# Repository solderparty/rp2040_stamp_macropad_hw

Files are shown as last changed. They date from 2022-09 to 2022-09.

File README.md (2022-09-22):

# RP2040 Stamp MacroPad (Flux Project)

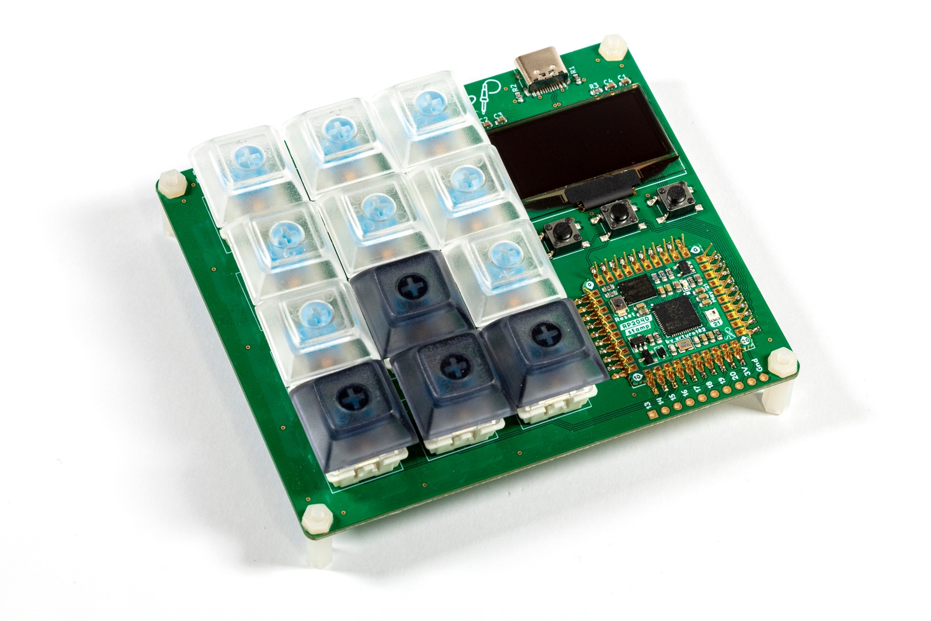
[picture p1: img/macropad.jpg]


Just add switches and key caps and you have a 3x4 MacroPad powered by the RP2040 Stamp, each key footprint includes a individually addressable **NeoPixel**, the board also comes with a **1.3" 128x64 OLED**, **three function buttons**, and extra GPIOs on an **optional header**. 

The board features a 3-in-1 combo RP2040 Stamp footprint, meaning you can solder the Stamp directly using the SMD pads, use 2mm pin headers, or using our FlexyPins!

You can program it using Arduino or CircuitPython.

# What does "Flux Project" mean?

At Solder Party, we always want to get interesting products in people's hands. However, releasing a product is no easy feat, we need to make sure everything is polished, provide documentation, examples, and extensive support.

With Flux, we want to streamline the process a bit, get fun projects into everyone's hands quicker.

Flux projects are more experimental in nature. While they are tested and verified, the documentation might not be fully there, and the examples might be very basic. 
Flux projects are targeted at people who are not scared to put a bit of extra work into getting the project to where they want it to end up.
These projects are also produced in smaller quantities, there is no guarantee there will be more produced in the future. Even if there is a new batch, it might differ from the initial version. 

These projects are in constant Flux, so to speak.

If there is enough interest, a Flux project might become a fully-fledged Solder Party product in the future, but there is no guarantee.

# Links

For more information visit https://flux.solder.party/

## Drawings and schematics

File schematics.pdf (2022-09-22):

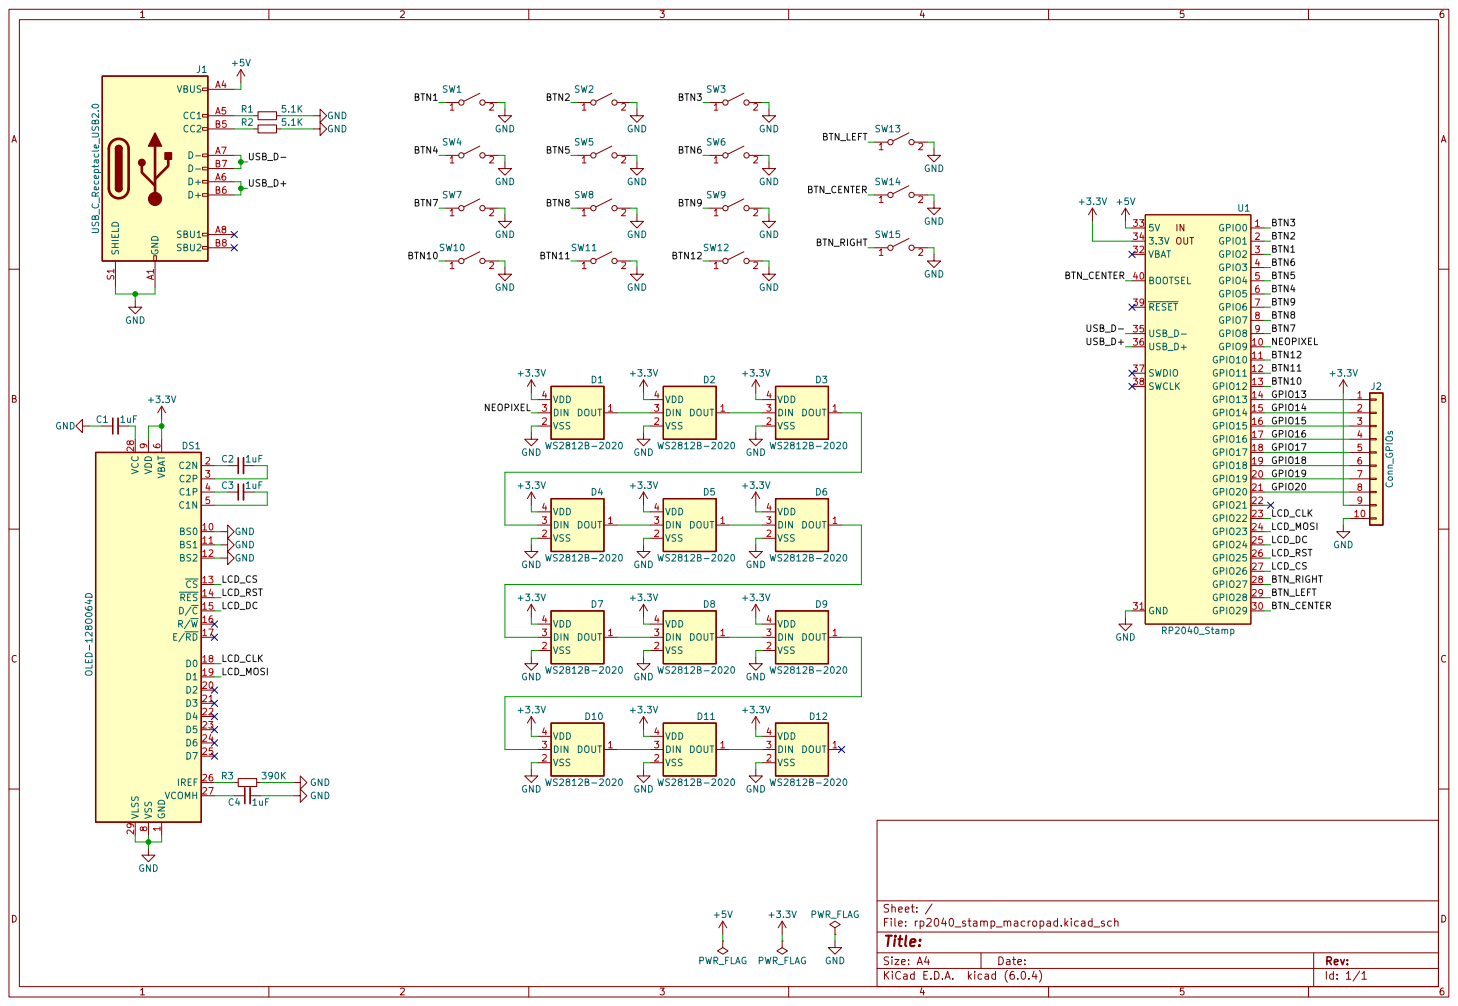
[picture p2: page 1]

J2 Conn_GPIOs GND GND GND GND GND

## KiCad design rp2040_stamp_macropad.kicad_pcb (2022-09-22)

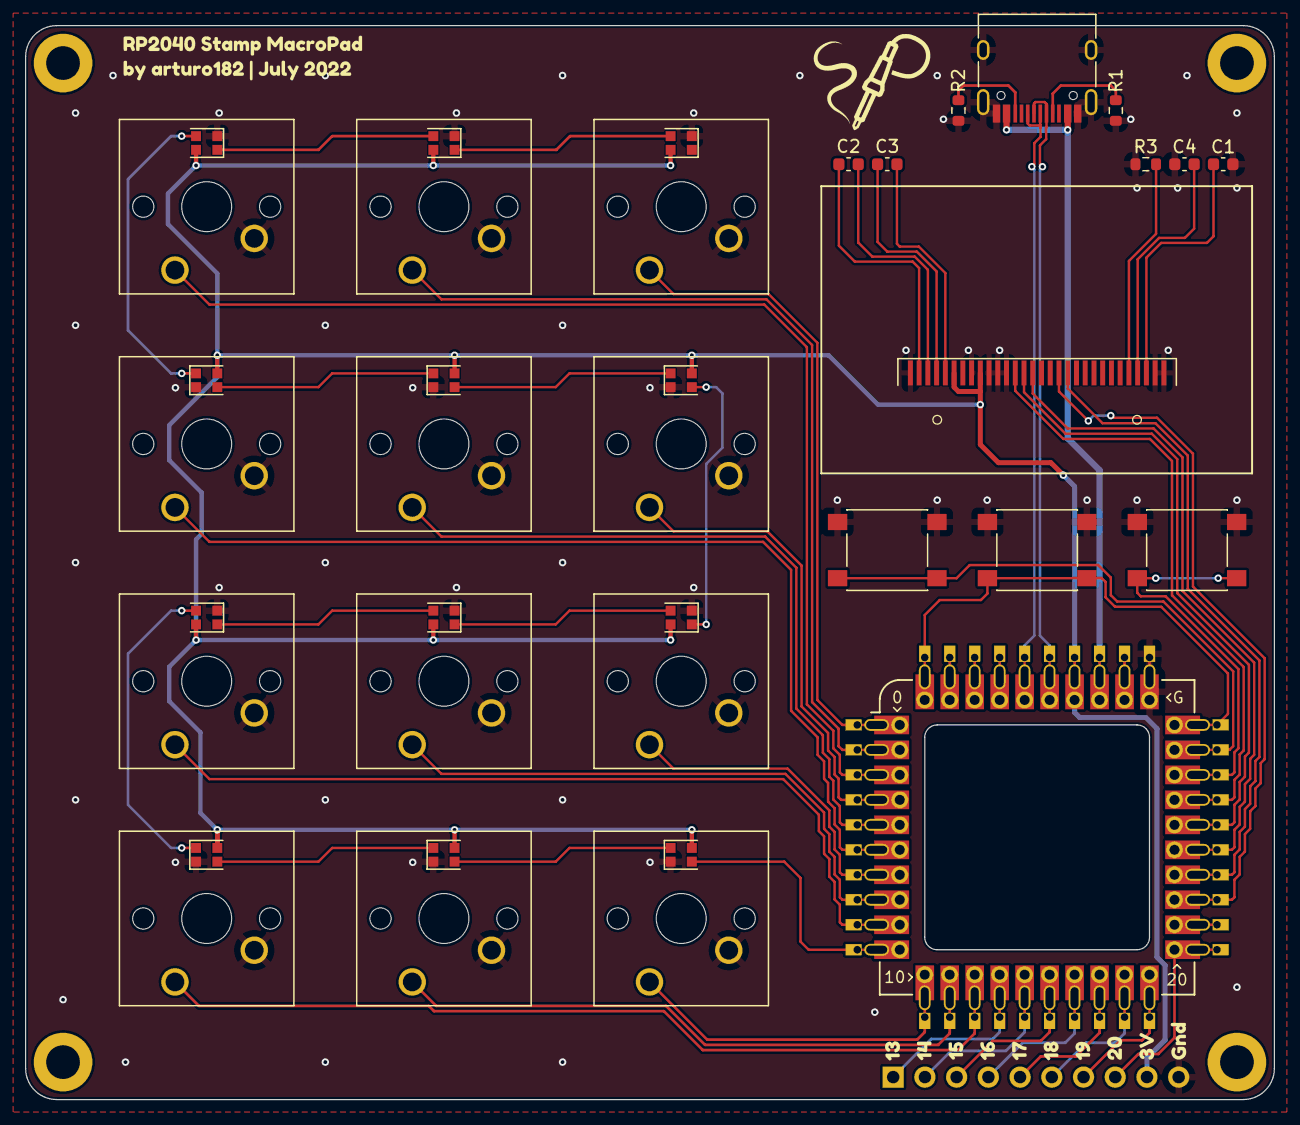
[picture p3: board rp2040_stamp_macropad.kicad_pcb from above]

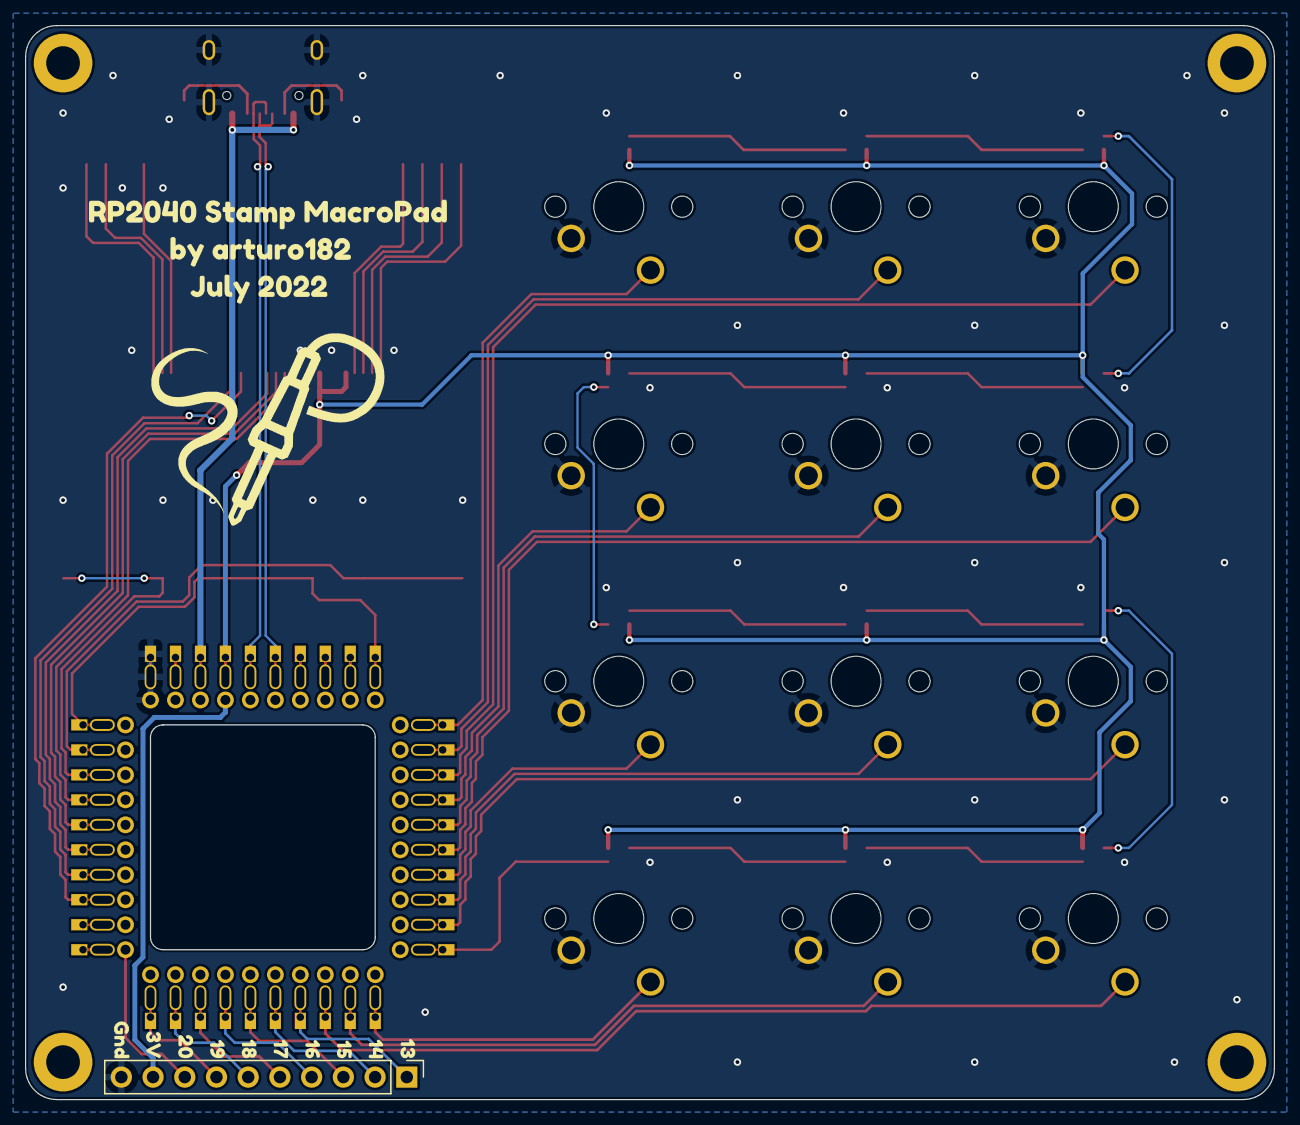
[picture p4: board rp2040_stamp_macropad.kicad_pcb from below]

Board: 2 copper layers, 100.0 x 86.0 mm, 60 parts (12 on the bottom side), 54 nets.

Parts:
C1, C2, C3, C4: 1uF; C_0603_1608Metric
D1, D2, D3, D4, D5, D6, D7, D8, D9, D10, D11, D12: WS2812B-2020
DS1: OLED-128O064D
J1: USB_C_Receptacle_USB2.0; USB_C_Receptacle_HRO_TYPE-C-31-M-12
J2: Conn_GPIOs; PinHeader_1x10_P2.54mm_Vertical
R1, R2: 5.1K; R_0603_1608Metric
R3: 390K; R_0603_1608Metric
SW1, SW2, SW3, SW4, SW5, SW6, SW7, SW8, SW9, SW10, SW11, SW12: SW_SPST; SW_Cherry_MX_1.00u_PCB
SW13: SW_LEFT; SW_SPST_PTS645
SW14: SW_CENTER; SW_SPST_PTS645
SW15: SW_RIGHT; SW_SPST_PTS645
U1: RP2040_Stamp; RP2040_Stamp_FlexyPin
kibuzzard-62C6D91C: G***; kibuzzard-62C6D91C
kibuzzard-62C6DD16: G***; kibuzzard-62C6DD16
kibuzzard-62DF06D5, kibuzzard-62DF06D5#2: G***; kibuzzard-62DF06D5
kibuzzard-62DF06DC, kibuzzard-62DF06DC#2: G***; kibuzzard-62DF06DC
kibuzzard-62DF061F, kibuzzard-62DF061F#2: G***; kibuzzard-62DF061F
kibuzzard-62DF063C, kibuzzard-62DF063C#2: G***; kibuzzard-62DF063C
kibuzzard-62DF064B, kibuzzard-62DF064B#2: G***; kibuzzard-62DF064B
kibuzzard-62DF0636, kibuzzard-62DF0636#2: G***; kibuzzard-62DF0636
kibuzzard-62DF0641, kibuzzard-62DF0641#2: G***; kibuzzard-62DF0641
kibuzzard-62DF0644, kibuzzard-62DF0644#2: G***; kibuzzard-62DF0644
kibuzzard-62DF0648, kibuzzard-62DF0648#2: G***; kibuzzard-62DF0648
kibuzzard-62DF0650, kibuzzard-62DF0650#2: G***; kibuzzard-62DF0650

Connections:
+3.3V: D1.4 (VDD), D2.4 (VDD), D3.4 (VDD), D4.4 (VDD), D5.4 (VDD), D6.4 (VDD), D7.4 (VDD), D8.4 (VDD), D9.4 (VDD), D10.4 (VDD), D11.4 (VDD), D12.4 (VDD), DS1.6 (VBAT), DS1.9 (VDD), J2.9, U1.34 (3.3V)
+5V: J1.A4 (VBUS), J1.A9 (VBUS), J1.B4 (VBUS), J1.B9 (VBUS), U1.33 (5V)
/BTN1: SW1.1 (A), U1.3 (GPIO2)
/BTN2: SW2.1 (A), U1.2 (GPIO1)
/BTN3: SW3.1 (A), U1.1 (GPIO0)
/BTN4: SW4.1 (A), U1.6 (GPIO5)
/BTN5: SW5.1 (A), U1.5 (GPIO4)
/BTN6: SW6.1 (A), U1.4 (GPIO3)
/BTN7: SW7.1 (A), U1.9 (GPIO8)
/BTN8: SW8.1 (A), U1.8 (GPIO7)
/BTN9: SW9.1 (A), U1.7 (GPIO6)
/BTN10: SW10.1 (A), U1.13 (GPIO12)
/BTN11: SW11.1 (A), U1.12 (GPIO11)
/BTN12: SW12.1 (A), U1.11 (GPIO10)
/BTN_CENTER: SW14.1 (A), U1.30 (GPIO29), U1.40 (BOOTSEL)
/BTN_LEFT: SW13.1 (A), U1.29 (GPIO28)
/BTN_RIGHT: SW15.1 (A), U1.28 (GPIO27)
/GPIO13: J2.1, U1.14 (GPIO13)
/GPIO14: J2.2, U1.15 (GPIO14)
/GPIO15: J2.3, U1.16 (GPIO15)
/GPIO16: J2.4, U1.17 (GPIO16)
/GPIO17: J2.5, U1.18 (GPIO17)
/GPIO18: J2.6, U1.19 (GPIO18)
/GPIO19: J2.7, U1.20 (GPIO19)
/GPIO20: J2.8, U1.21 (GPIO20)
/LCD_CLK: DS1.18 (D0), U1.23 (GPIO22)
/LCD_CS: DS1.13 (~CS), U1.27 (GPIO26)
/LCD_DC: DS1.15 (D/~C), U1.25 (GPIO24)
/LCD_MOSI: DS1.19 (D1), U1.24 (GPIO23)
/LCD_RST: DS1.14 (~RES), U1.26 (GPIO25)
/NEOPIXEL: D1.3 (DIN), U1.10 (GPIO9)
/USB_D+: J1.A6 (D+), J1.B6 (D+), U1.36 (USB_D+)
/USB_D-: J1.A7 (D-), J1.B7 (D-), U1.35 (USB_D-)
GND: C1.1, C4.2, D1.2 (VSS), D2.2 (VSS), D3.2 (VSS), D4.2 (VSS), D5.2 (VSS), D6.2 (VSS), D7.2 (VSS), D8.2 (VSS), D9.2 (VSS), D10.2 (VSS), D11.2 (VSS), D12.2 (VSS), DS1.1 (GND), DS1.8 (VSS), DS1.10 (BS0), DS1.11 (BS1), DS1.12 (BS2), DS1.29 (VLSS), DS1.30 (GND), J1.A1 (GND), J1.A12 (GND), J1.B1 (GND), J1.B12 (GND), J1.S1 (SHIELD), J2.10, R1.2, R2.2, R3.2, SW1.2 (B), SW2.2 (B), SW3.2 (B), SW4.2 (B), SW5.2 (B), SW6.2 (B), SW7.2 (B), SW8.2 (B), SW9.2 (B), SW10.2 (B), SW11.2 (B), SW12.2 (B), SW13.2 (B), SW14.2 (B), SW15.2 (B), U1.31 (GND)
unnamed: C1.2, DS1.28 (VCC)
unnamed: C2.1, DS1.2 (C2N)
unnamed: C2.2, DS1.3 (C2P)
unnamed: C3.1, DS1.4 (C1P)
unnamed: C3.2, DS1.5 (C1N)
unnamed: C4.1, DS1.27 (VCOMH)
unnamed: D1.1 (DOUT), D2.3 (DIN)
unnamed: D2.1 (DOUT), D3.3 (DIN)
unnamed: D3.1 (DOUT), D4.3 (DIN)
unnamed: D4.1 (DOUT), D5.3 (DIN)
unnamed: D5.1 (DOUT), D6.3 (DIN)
unnamed: D6.1 (DOUT), D7.3 (DIN)
unnamed: D7.1 (DOUT), D8.3 (DIN)
unnamed: D8.1 (DOUT), D9.3 (DIN)
unnamed: D10.1 (DOUT), D11.3 (DIN)
unnamed: D9.1 (DOUT), D10.3 (DIN)
unnamed: D11.1 (DOUT), D12.3 (DIN)
unnamed: DS1.26 (IREF), R3.1
unnamed: J1.A5 (CC1), R1.1
unnamed: J1.B5 (CC2), R2.1

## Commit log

2022-07-07 Rev 1
    [rp2040_stamp_macropad.kicad_pcb, rp2040_stamp_macropad.kicad_sch]
2022-09-22 Rev 2
    [rp2040_stamp_macropad.kicad_pcb, rp2040_stamp_macropad.kicad_sch]
